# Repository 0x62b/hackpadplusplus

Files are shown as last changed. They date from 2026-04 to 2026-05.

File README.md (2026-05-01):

# Hackpad++
6-key hot-swappable RGB backlit macropad based on Seeed Studio Xiao NRF52840. Uses ZMK for firmware.
400mAh battery, supports wireless BLE HID operation. I made this to use up some spare parts and learn more about ZMK.

Rn the firmware is in a really really really stripped down state because I want to get the physical thing before trying to make more firmware since it keeps breaking the build

According to ZMK's [power profiler](https://zmk.dev/power-profiler) we should get about 21 hours of battery life with the RGB at 20% brightness

## Repo Structure
CAD files in `cad/`\
KiCad design files in `PCB/`\
Production gerbers in `PCB/gerbers`\
Firmware in `firmware/`\
BOM at `bom.csv`\
Case Onshape design [here](https://cad.onshape.com/documents/916857c7e80611f775a72b60/w/b9c69dbfc296334dd1ffd629/e/9b910e13e67ad3b8cb3a877d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)

## 3D Models
https://grabcad.com/library/oled-0-91-128x32-1
https://grabcad.com/library/seeed-studio-xiao-nrf52840-sense-1
https://grabcad.com/library/kailh-polia-switch-cherry-mx-compatible-1
https://grabcad.com/library/11mm-metal-shaft-rotary-encoders-tht-vertical-w-push-on-switch-1
https://grabcad.com/library/dsa-keycap-for-cherry-mx-switches-1

# Assembly
Prerequisites: solder the PCB and print the case
1. put switches into sockets
2. put PCB assembly into bottom case
3. put top case over the assembly
4. screw in the top case with M3 screws
5. attach keycaps to switches
6. flash firmware according to ZMK docs
7. yay

## Cost
BOM: 17.38 USD\
PCB: 4 USD + 1.5 USD shipping\
Total: 22.88 USD

|Item |Unit Price (AUD)|Quantity|Extended Price (AUD)|Extended Price(USD)|Notes |Link |
|---|---|---|---|---|---|---|
|Switches |0 |6 |0 |0 |Owned |https://www.aliexpress.com/item/1005007983672026.html |
|Hotswap sockets |0 |6 |0 |0 |Extra from keeb |https://www.aliexpress.com/item/1005007232040760.html |
|Diodes |0 |6 |0 |0 |Extra from keeb |https://www.aliexpress.com/item/1005006323468521.html |
|LEDs |0 |6 |0 |0 |Owned - link is example |https://www.aliexpress.com/item/1005005193716172.html |
|Xiao |19.25 |1 |19.25 |13.77 |ITS CHEAPER THAN ALIEXPRESS IVE CHECKED|https://core-electronics.com.au/seeed-studio-xiao-nrf52840-pre-soldered-bluetooth-5-0-ble-wireless-iot-microcontroller-board.html|
|Keycaps |0 |6 |0 |0 |Owned - link is example |https://aliexpress.com/item/1005011909872629.html |
|OLED |0 |1 |0 |0 |Owned |https://www.lcsc.com/product-detail/C5248081.html |
|Battery |5.05 |1 |5.05 |3.61 |N/A |https://core-electronics.com.au/polymer-lithium-ion-battery-400mah-38456.html |
|M3 heatset inserts|0 |4 |0 |0 |owned |N/A |
|M3x10 screws |0 |4 |0 |0 |owned |N/A |
|PCB |N/A |1 |N/A |6.5 |N/A |https://jlcpcb.com |

## Images
### Schematic
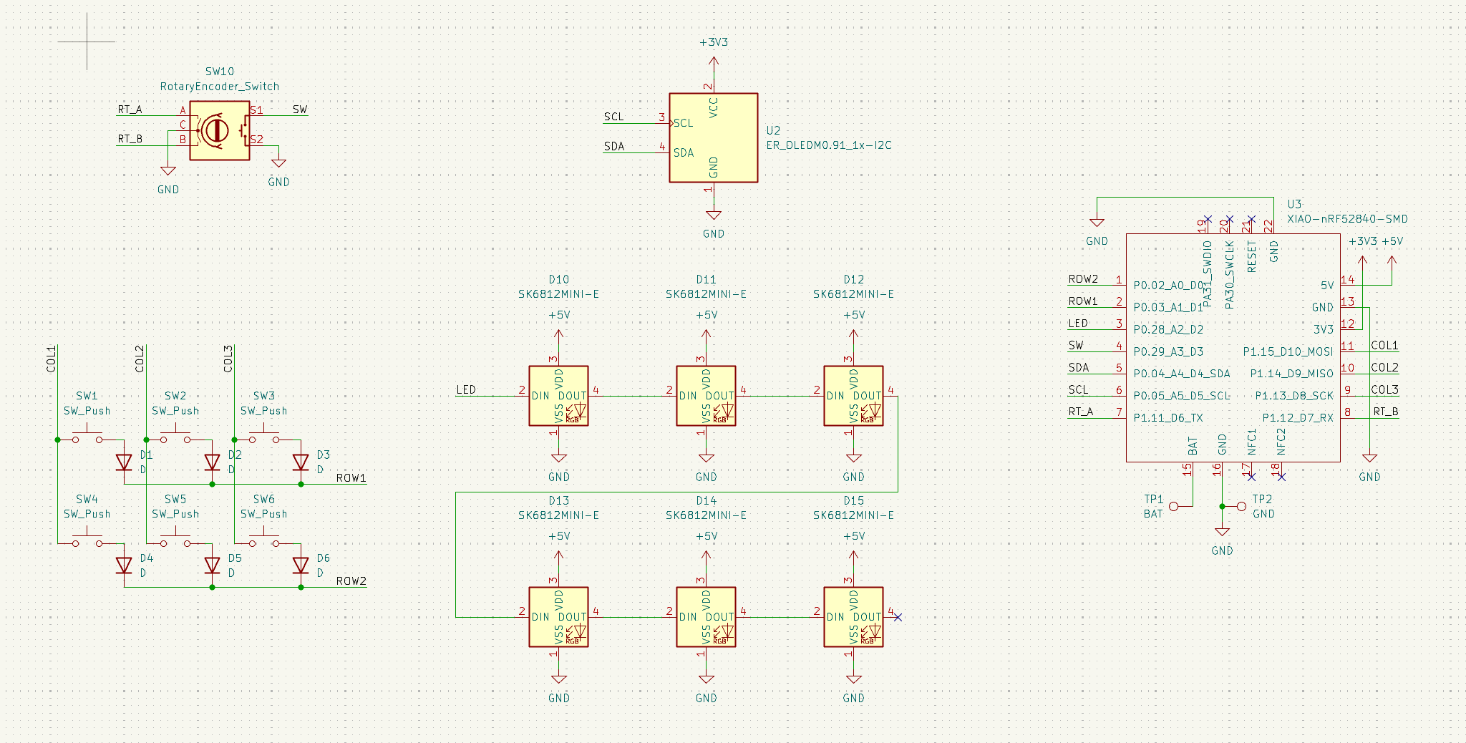
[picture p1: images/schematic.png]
Schematic

### PCB layout
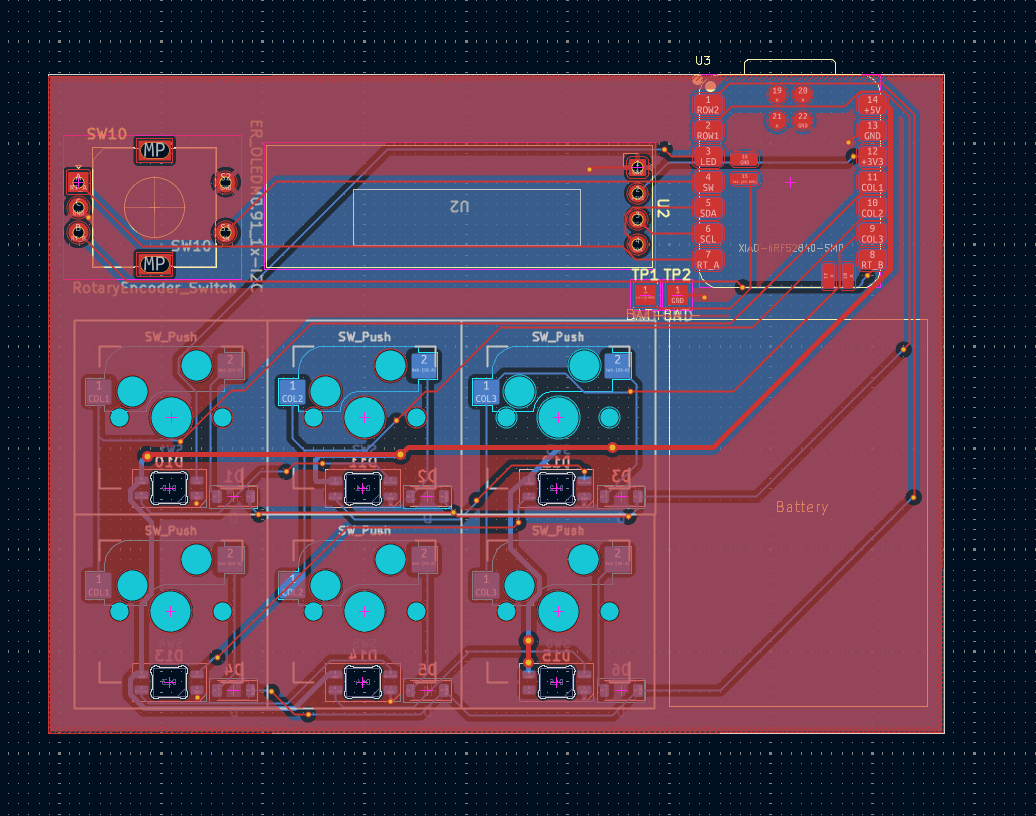
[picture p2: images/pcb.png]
PCB

### PCB render
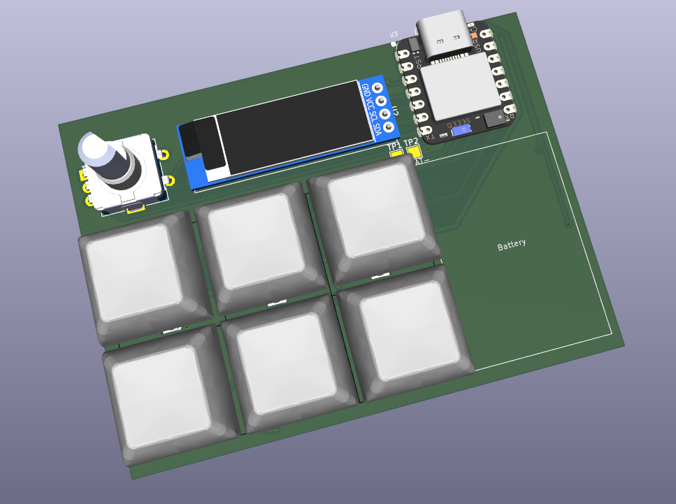
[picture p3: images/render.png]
Full PCB render

### Full render
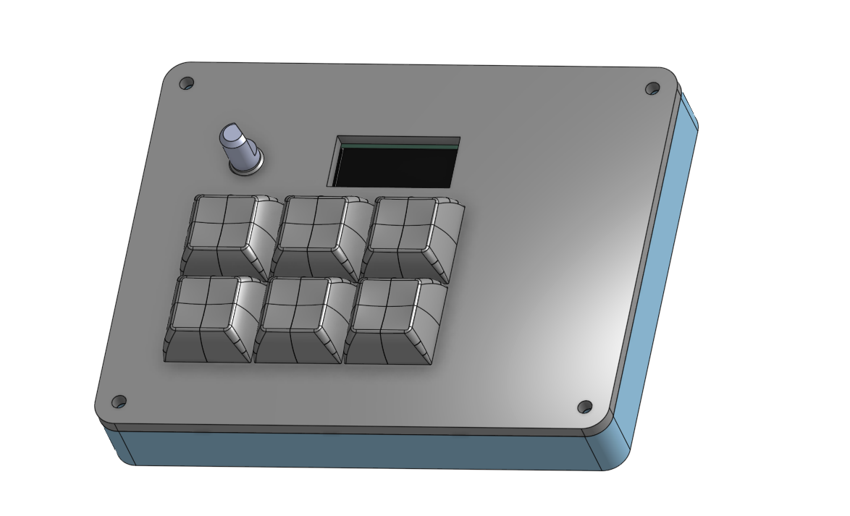
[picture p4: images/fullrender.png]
Case + PCB render

### Zine page


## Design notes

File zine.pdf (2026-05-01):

# Hackpad++

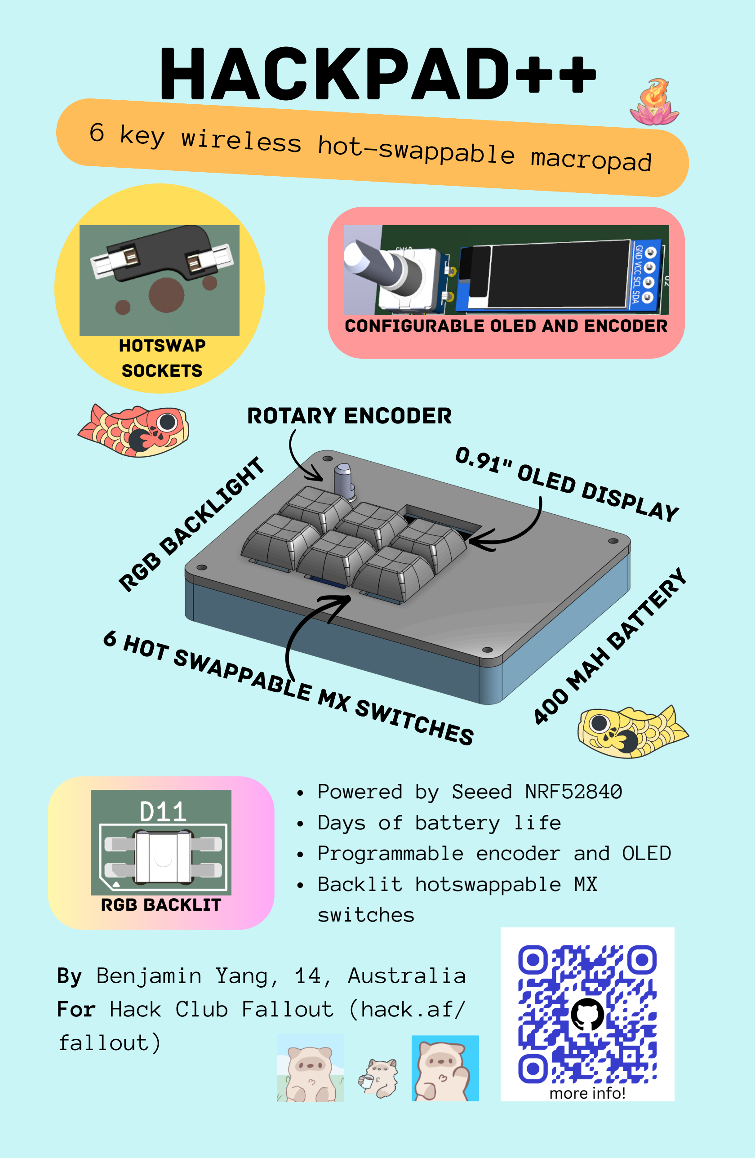
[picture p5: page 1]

## 6 Hot swappable MX switches

## 0.91" OLED display

### Rotary encoder

## 400 mAh batter

RG
y

## B backlight

### 6 key wireless hot-swappable macropad

Hotswap
sockets

RGB backlit

Configurable OLED and encoder

By Benjamin Yang, 14, Australia For Hack Club Fallout (hack.af/ fallout)

Powered by Seeed NRF52840
Days of battery life
Programmable encoder and OLED Backlit hotswappable MX
switches

more info!

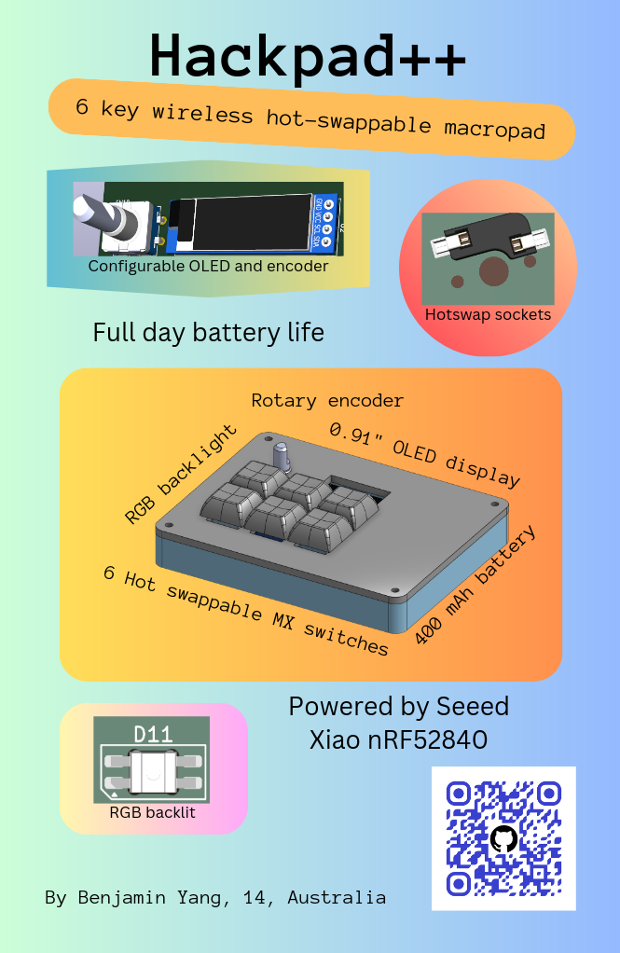
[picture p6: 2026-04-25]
images/zine.png

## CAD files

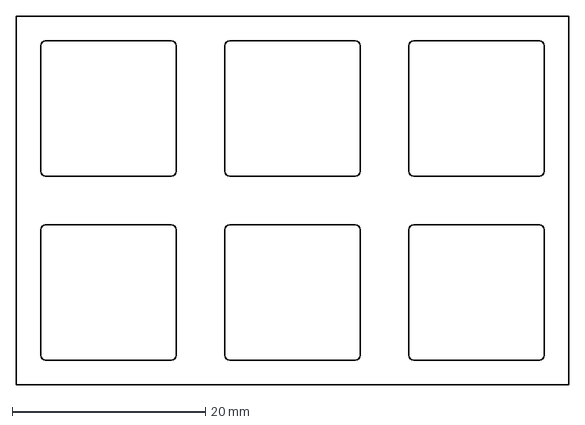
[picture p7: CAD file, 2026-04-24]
CAD/plate-2026-04-24T11_46_47.121Z.dxf
57.1 x 38.1 mm

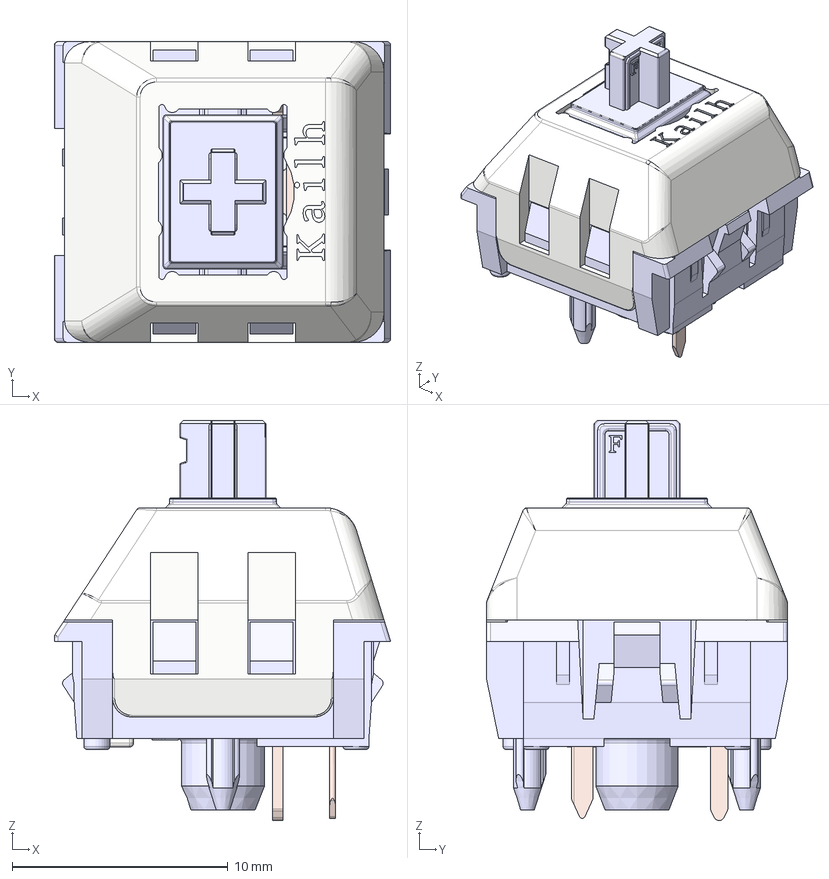
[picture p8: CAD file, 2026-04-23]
PCB/models/Kailh Polia.step
15.6 x 14.0 x 18.5 mm
Housing
ThickContact
SpringContact
Stem
Lid

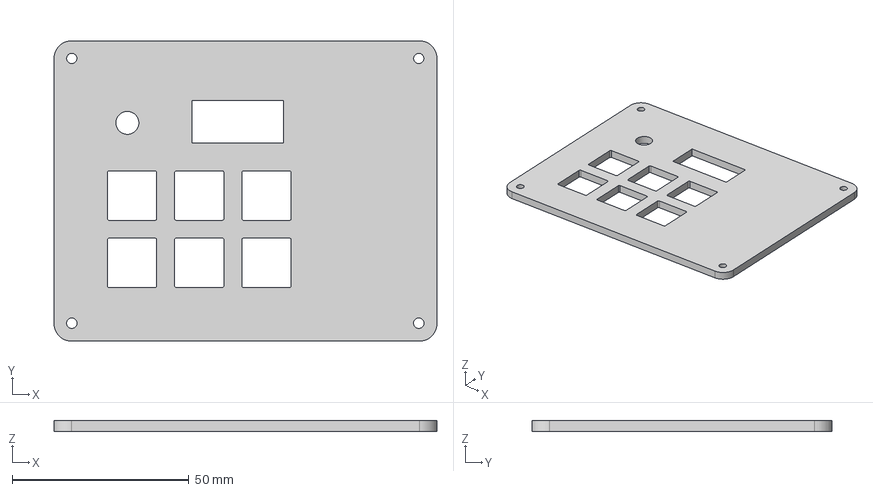
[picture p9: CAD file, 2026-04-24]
CAD/hackpad top case.step
108.5 x 85.1 x 3.00 mm

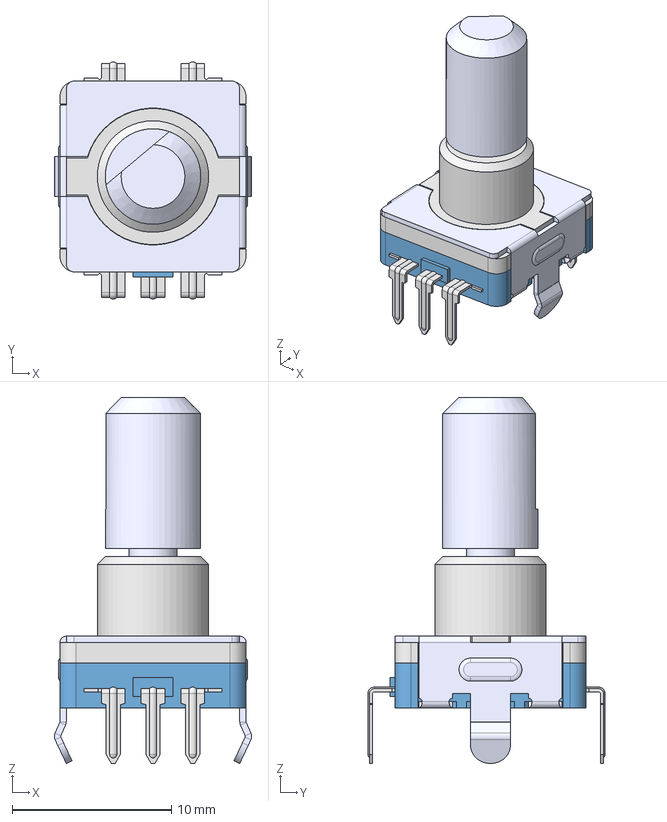
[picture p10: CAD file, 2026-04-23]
PCB/models/EC11-THT-15F-blue.step
12.4 x 14.9 x 23.0 mm
Lb5
15F
EC11-Housing-THT

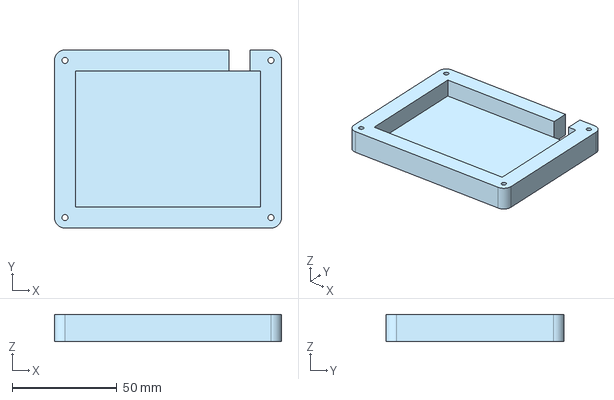
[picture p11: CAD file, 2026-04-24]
CAD/hackpad bottom case.step
108.3 x 85.0 x 13.0 mm

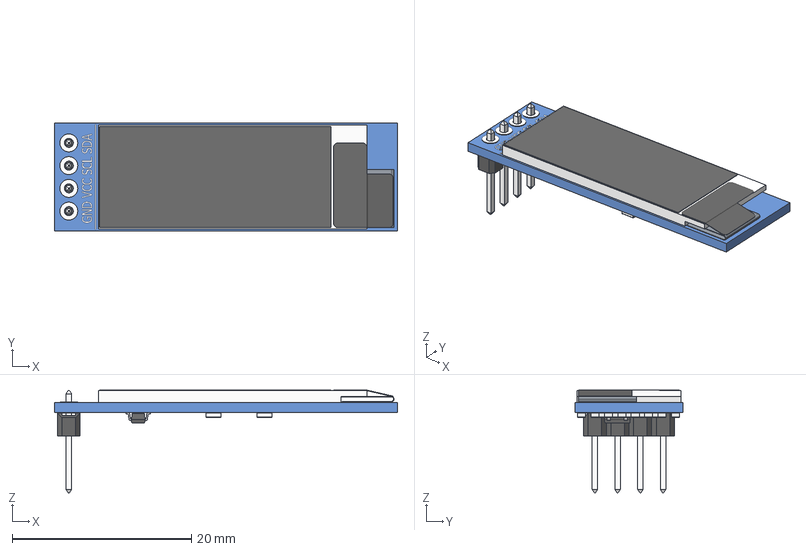
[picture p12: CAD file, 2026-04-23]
PCB/models/OLED_0.91_128x32.stp
38.3 x 12.1 x 11.5 mm
OLED_0.91_128x32
Pin Header 4 x 1 TH 2.54mm Pitch
RESC-0603 x 13
2SD0601A

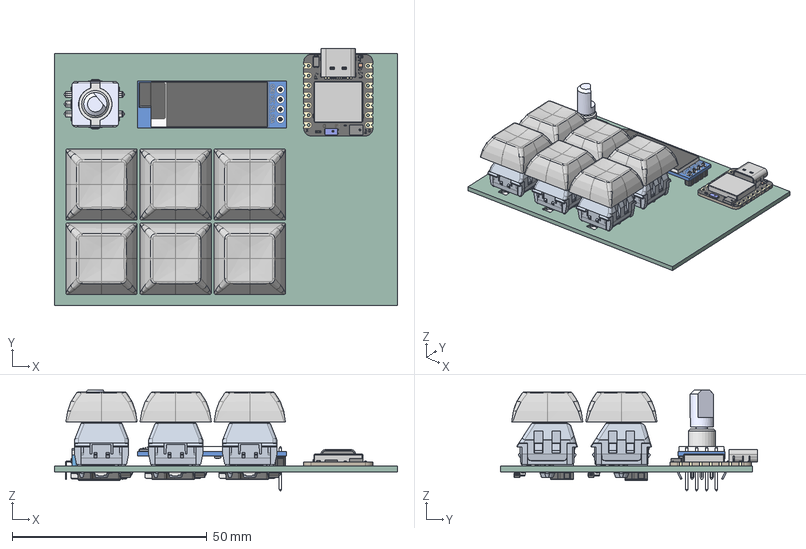
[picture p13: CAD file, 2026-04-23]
CAD/board.step
88.2 x 66.1 x 25.9 mm
OLED_0.91_128x32
Pin Header 4 x 1 TH 2.54mm Pitch
RESC-0603 x 13
2SD0601A
BOSS-EXTRUDE14_8_
BOSS-EXTRUDE7_4_
BOSS-EXTRUDE7_3_
BOSS-EXTRUDE14_4_
BOSS-EXTRUDE14_2_
BOSS-EXTRUDE14_11_
BOSS-EXTRUDE7_7_
BOSS-EXTRUDE14_9_
BOSS-EXTRUDE14_3_
BOSS-EXTRUDE14_7_
MIRROR2
BOSS-EXTRUDE14_5_
BOSS-EXTRUDE14_12_
BOSS-EXTRUDE7_8_
BOSS-EXTRUDE7_1_
BOSS-EXTRUDE14_10_
BOSS-EXTRUDE7_9_
BOSS-EXTRUDE14_6_
BOSS-EXTRUDE14_1_
BOSS-EXTRUDE7_6_
BOSS-EXTRUDE7_2_
CUT-EXTRUDE5
BOSS-EXTRUDE7_5_
Shield
Pins
CAP x 2
ANT1
Silkscreen
CAP 3
LED
USR
2 v1
EC11-Base
EC11-Shaft-F
EC11-Housing-THT
Pin1 x 6
Pin2 x 6
Pin3 x 6
Pin4 x 6
MX-Hotswap-Socket x 6
board 1.6.1 x 6
DSA_Keycap_CherryMX x 6
D_SOD-123 x 6
Hackpad++_PCB

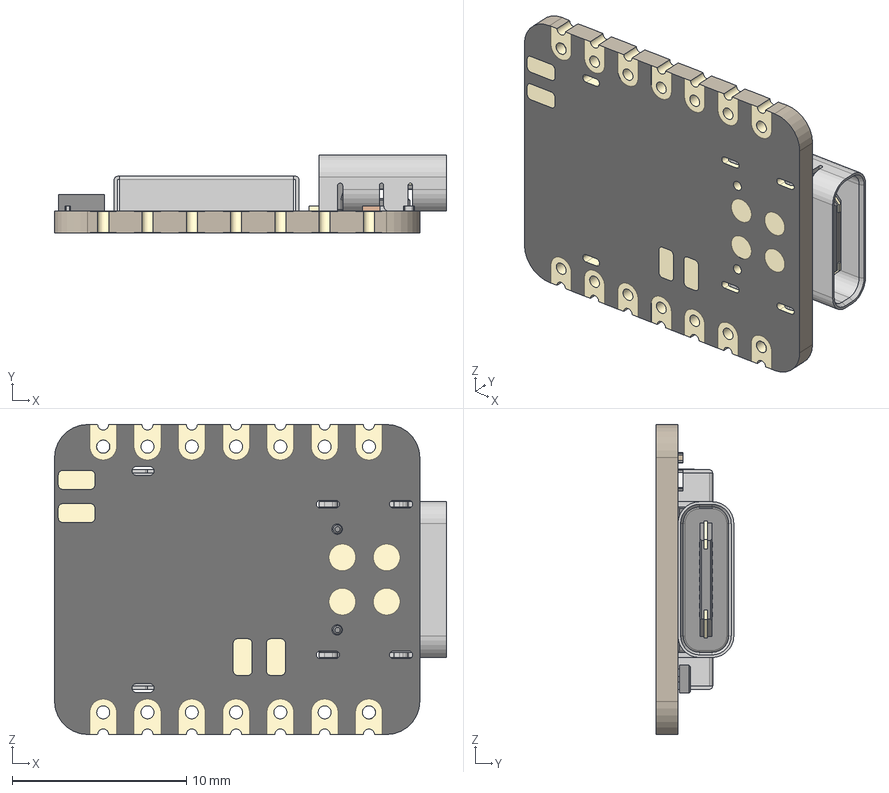
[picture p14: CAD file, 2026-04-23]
PCB/models/XIAO-nRF52840 v15.step
22.5 x 4.46 x 17.8 mm
BOSS-EXTRUDE14_8_
BOSS-EXTRUDE7_4_
BOSS-EXTRUDE7_3_
BOSS-EXTRUDE14_4_
BOSS-EXTRUDE14_2_
BOSS-EXTRUDE14_11_
BOSS-EXTRUDE7_7_
BOSS-EXTRUDE14_9_
BOSS-EXTRUDE14_3_
BOSS-EXTRUDE14_7_
MIRROR2
BOSS-EXTRUDE14_5_
BOSS-EXTRUDE14_12_
BOSS-EXTRUDE7_8_
BOSS-EXTRUDE7_1_
BOSS-EXTRUDE14_10_
BOSS-EXTRUDE7_9_
BOSS-EXTRUDE14_6_
BOSS-EXTRUDE14_1_
BOSS-EXTRUDE7_6_
BOSS-EXTRUDE7_2_
CUT-EXTRUDE5
BOSS-EXTRUDE7_5_
Shield
Pins
CAP x 2
ANT1
Silkscreen
CAP 3
LED
USR
2 v1

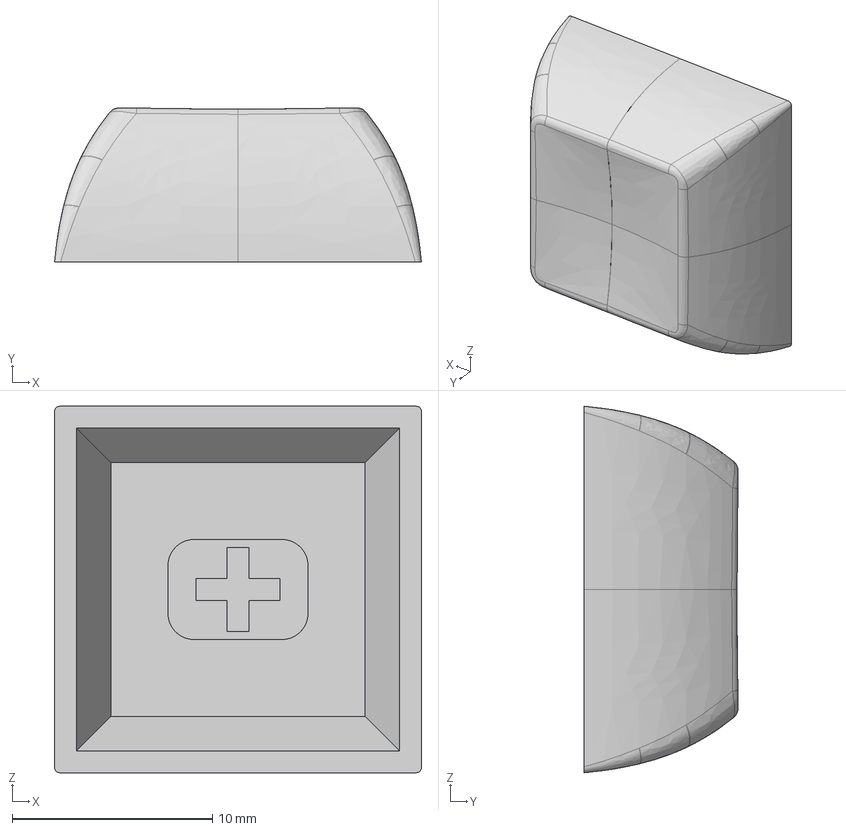
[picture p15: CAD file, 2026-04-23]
PCB/models/DSA_Keycap_CherryMX.step
18.3 x 7.69 x 18.3 mm

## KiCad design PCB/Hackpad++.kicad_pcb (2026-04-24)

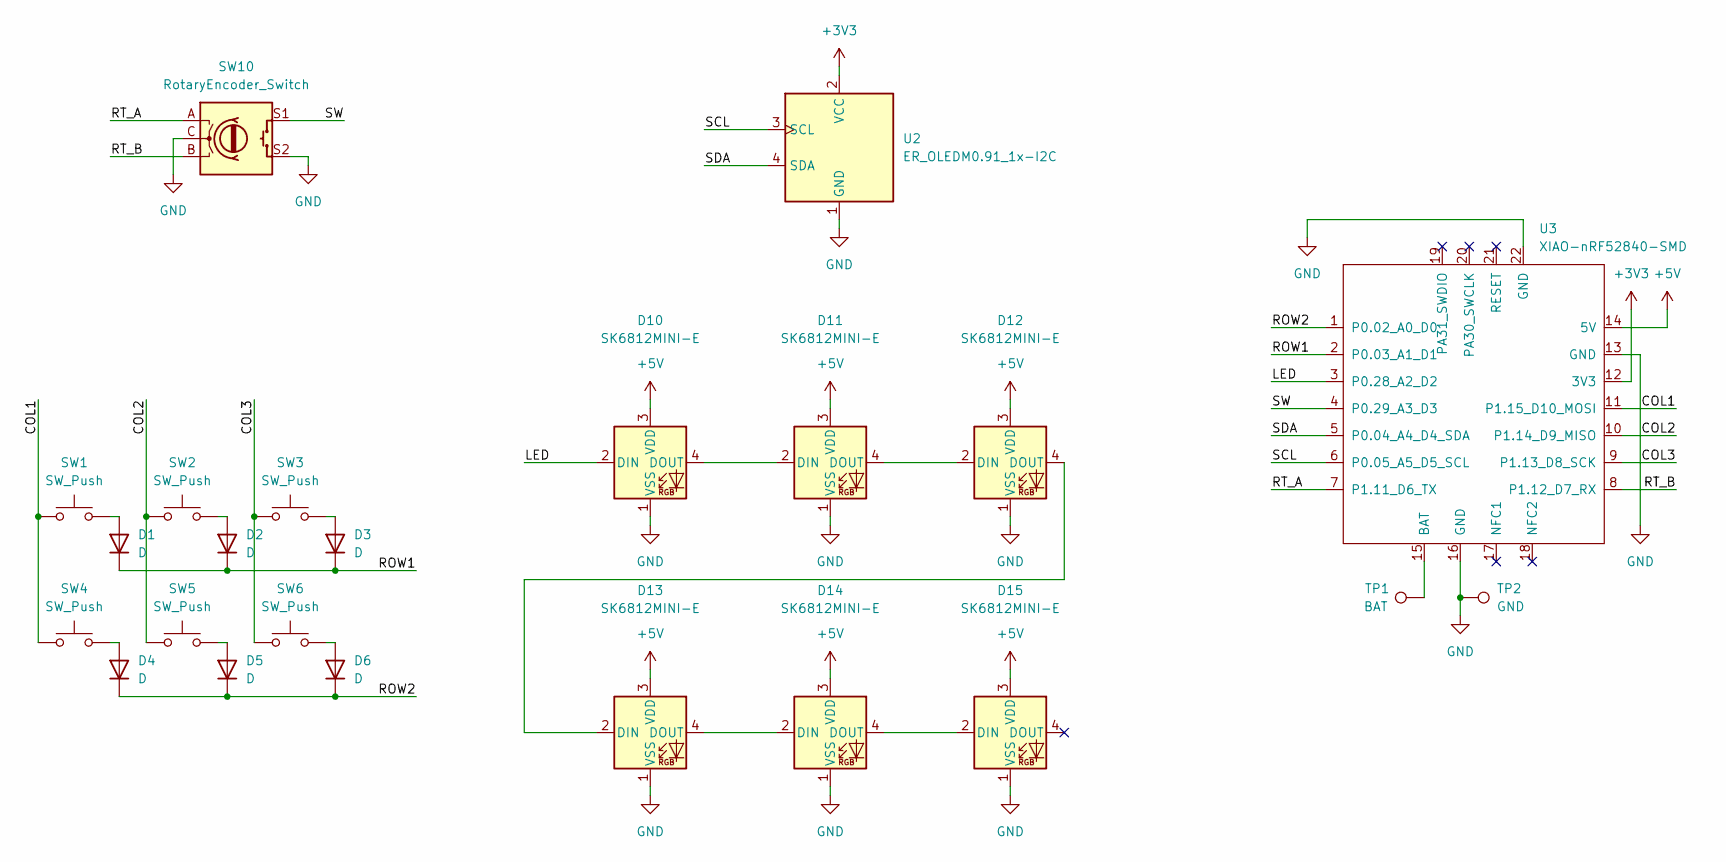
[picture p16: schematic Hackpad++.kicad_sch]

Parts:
D1, D2, D3, D4, D5, D6: D; D_SOD-123
D10, D11, D12, D13, D14, D15: SK6812MINI-E; LED_SK6812MINI-E_3.2x2.8mm_P1.5mm_ReverseMount
SW1, SW2, SW3, SW4, SW5, SW6: SW_Push; MX-Hotswap-1U
SW10: RotaryEncoder_Switch; RotaryEncoder_Alps_EC11E-Switch_Vertical_H20mm
TP1: BAT; TestPoint_Pad_2.0x2.0mm
TP2: GND; TestPoint_Pad_2.0x2.0mm
U2: ER_OLEDM0.91_1x-I2C
U3: XIAO-nRF52840-SMD

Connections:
+3V3: U2.2 (VCC), U3.12 (3V3)
+5V: D10.3 (VDD), D11.3 (VDD), D12.3 (VDD), D13.3 (VDD), D14.3 (VDD), D15.3 (VDD), U3.14 (5V)
/COL1: SW1.1, SW4.1, U3.11 (P1.15_D10_MOSI)
/COL2: SW2.1, SW5.1, U3.10 (P1.14_D9_MISO)
/COL3: SW3.1, SW6.1, U3.9 (P1.13_D8_SCK)
/LED: D10.2 (DIN), U3.3 (P0.28_A2_D2)
/ROW1: D1.1 (K), D2.1 (K), D3.1 (K), U3.2 (P0.03_A1_D1)
/ROW2: D4.1 (K), D5.1 (K), D6.1 (K), U3.1 (P0.02_A0_D0)
/RT_A: SW10.A, U3.7 (P1.11_D6_TX)
/RT_B: SW10.B, U3.8 (P1.12_D7_RX)
/SCL: U2.3 (SCL), U3.6 (P0.05_A5_D5_SCL)
/SDA: U2.4 (SDA), U3.5 (P0.04_A4_D4_SDA)
/SW: SW10.S1, U3.4 (P0.29_A3_D3)
GND: D10.1 (VSS), D11.1 (VSS), D12.1 (VSS), D13.1 (VSS), D14.1 (VSS), D15.1 (VSS), SW10.C, SW10.S2, TP2.1 (1_1), U2.1 (GND), U3.13 (GND), U3.16 (GND), U3.22 (GND)
unnamed: D1.2 (A), SW1.2
unnamed: D2.2 (A), SW2.2
unnamed: D3.2 (A), SW3.2
unnamed: D4.2 (A), SW4.2
unnamed: D5.2 (A), SW5.2
unnamed: D6.2 (A), SW6.2
unnamed: D10.4 (DOUT), D11.2 (DIN)
unnamed: D11.4 (DOUT), D12.2 (DIN)
unnamed: D12.4 (DOUT), D13.2 (DIN)
unnamed: D13.4 (DOUT), D14.2 (DIN)
unnamed: D14.4 (DOUT), D15.2 (DIN)
unnamed: TP1.1 (1_1), U3.15 (BAT)

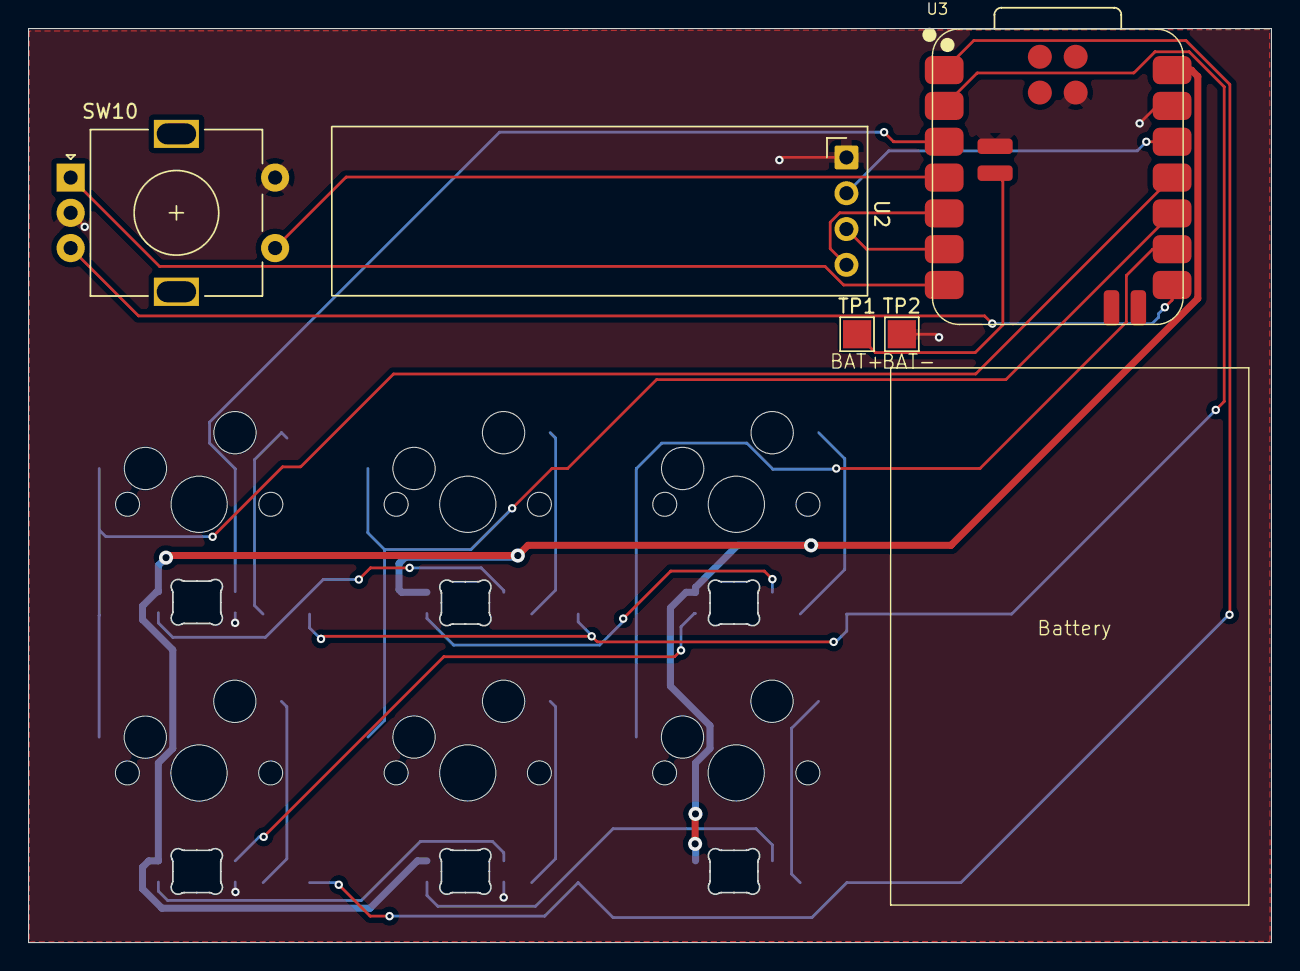
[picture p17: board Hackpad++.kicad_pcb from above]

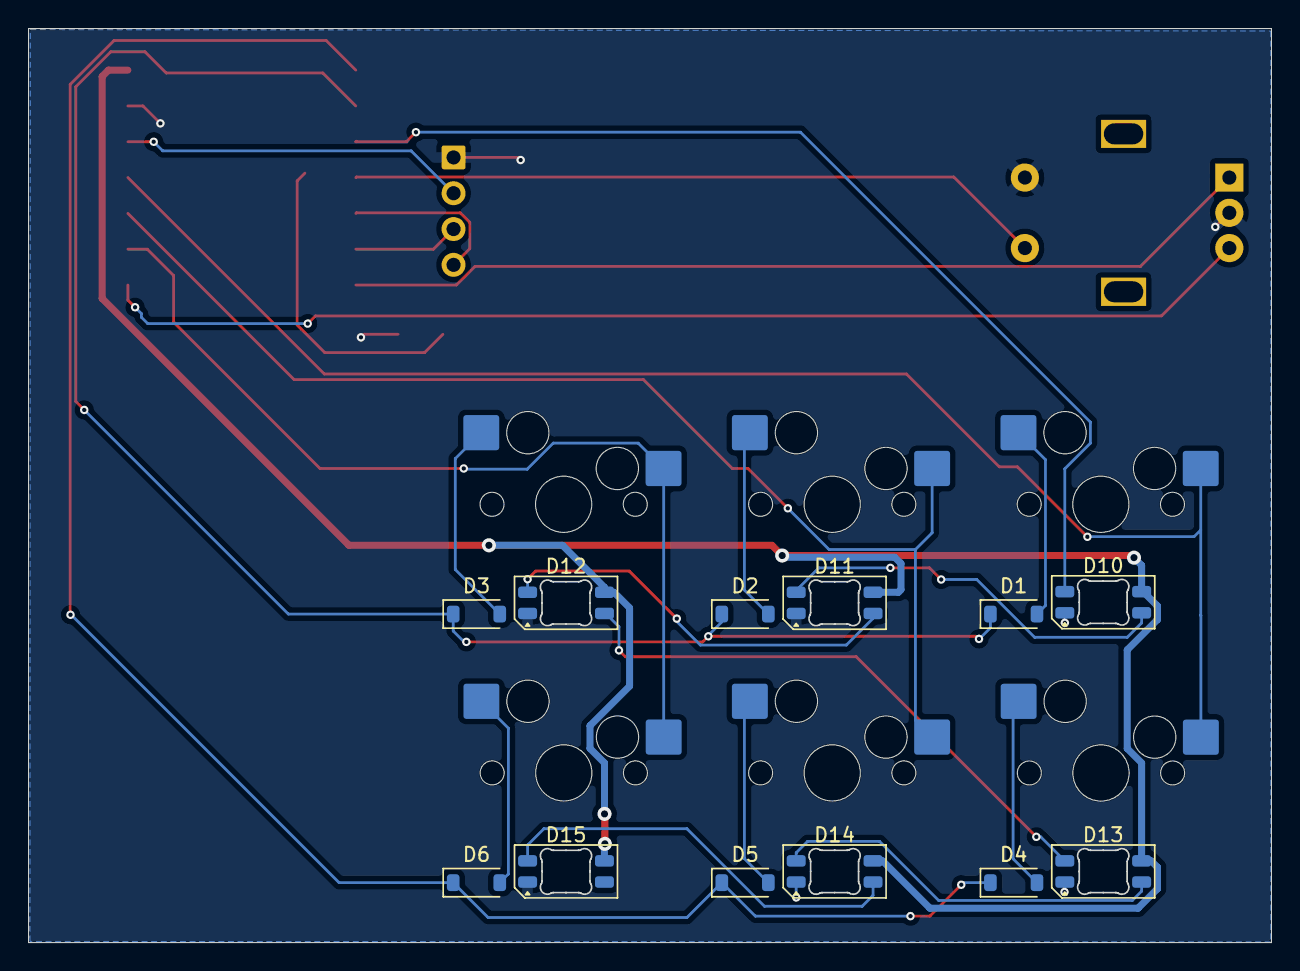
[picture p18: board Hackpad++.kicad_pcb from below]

Board: 2 copper layers, 88.2 x 64.8 mm, 23 parts (18 on the bottom side), 26 nets.

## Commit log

2026-04-24 add case and plate cad files
    [hackpad bottom case.step, hackpad top case.step, plate-2026-04-24T11_46_47.121Z.dxf]
2026-04-24 add onshape link
    [Hackpad++.kicad_pcb]
2026-04-24 add full assembly step
2026-04-24 add full assembly render image
2026-04-24 add links to bom
    [bom.csv]
2026-04-29 add assembly instructions
    people who needed this are the people who need instructions on a shampoo bottle
